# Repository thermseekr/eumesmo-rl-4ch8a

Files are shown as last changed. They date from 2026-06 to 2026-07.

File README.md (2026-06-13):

# eumesmo-rl-4ch8a

Relay board with 4x 24 VDC NO relays. This board is designed to be used togheter with [eumesmo-io-24v16ch](https://github.com/thermseekr/eumesmo-io-24v16ch), but can be driven by any 24V control circuit compatible with NPN inputs. It uses Omron 10A relays and is limited to 8A/channel per copper trace capacity.

The board is compatible with the SP7 DIN rail system from Metaltex.

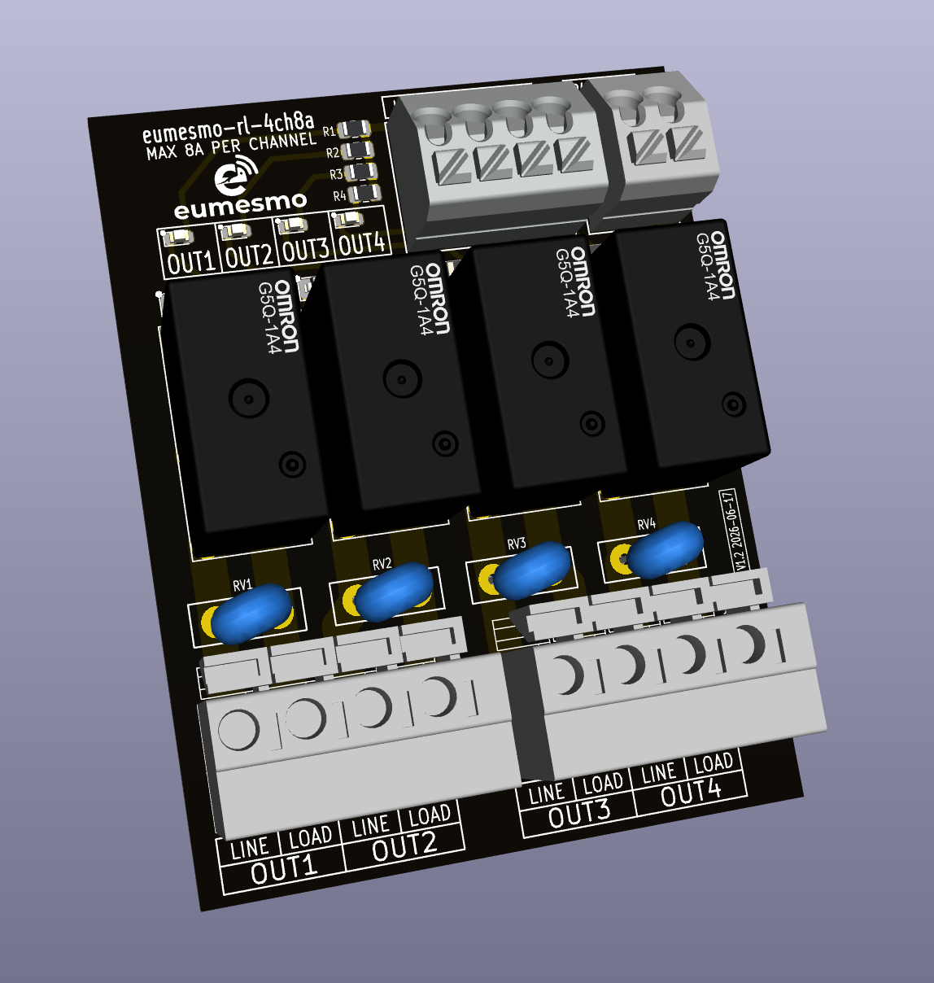
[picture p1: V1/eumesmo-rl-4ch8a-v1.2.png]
eumesmo-rl-4ch8a


## VERSION HISTORY

V1.2 - 2026/06/13 - Repository renamed from RELAY-24V-4CH-8A to eumesmo-rl-4ch8A to align the design with the eumesmo line of building automation products.

V1.1 - 2026/06/02 - Input terminal blocks replaced from 2.54mm to 3.5mm pitch for easier installation in the field.

V1.0 - 2024-11-23 - Initial release.

## LICENSE

This project is licensed under the [Creative Commons BY-NC 4.0 License](https://creativecommons.org/licenses/by-nc/4.0/).
Commercial use is not permitted without prior written consent. See the [LICENSE.txt](LICENSE.txt) file for details.

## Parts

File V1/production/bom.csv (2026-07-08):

Designator | Footprint | Quantity | Value | LCSC Part #
D1, D3, D5, D7 | 0603 | 4 | WHITE | C2290
D2, D4, D6, D8 | D_SOD-123 | 4 | 1N4148 | C81598
J1 | TerminalBlock_Wago_250-202_1x02_P3.5mm_45Degree | 1 | 250-202 | C2898744
J2 | TerminalBlock_Wago_250-204_1x04_P3.5mm_45Degree | 1 | 250-204 | C2898746
J3, J4 | TerminalBlock_Dibo_DB142V-5.08-4P_1x04_P5.08mm_Vertical | 2 | DB142V-5.08-4P | C2898701
K1, K2, K3, K4 | Relay_SPST_Omron-G5Q-1A | 4 | G5Q-1A4-DC24V | C2931104
R1, R2, R3, R4 | 0805 | 4 | 10k/125mW | C17414
RV1, RV2, RV3, RV4 | RV_Disc_D9.50mm_W3.6mm_P5.08mm | 4 | 275VAC | C2761646

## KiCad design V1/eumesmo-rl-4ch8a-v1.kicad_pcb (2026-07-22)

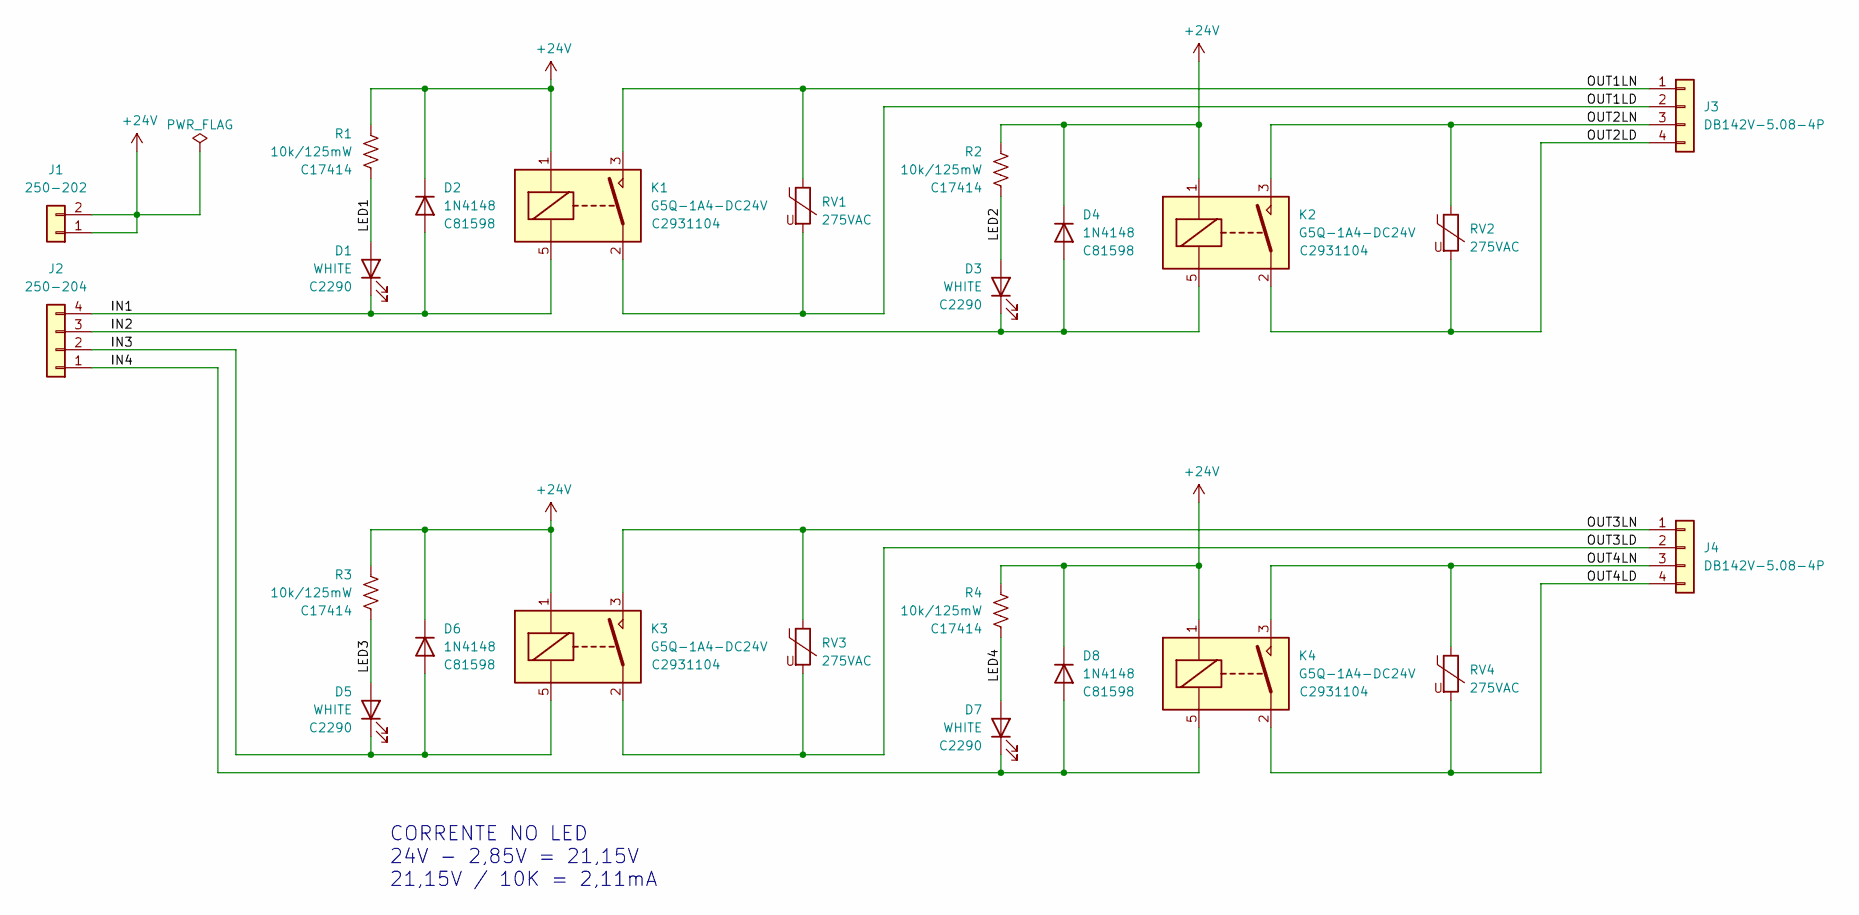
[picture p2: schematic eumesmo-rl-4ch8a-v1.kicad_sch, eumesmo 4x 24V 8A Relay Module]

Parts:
D1, D3, D5, D7: WHITE; LED_0603_1608Metric; Mfr PN KT-0603W; LCSC Part # C2290
D2, D4, D6, D8: 1N4148; D_SOD-123; Mfr PN 1N4148W; LCSC Part # C81598
J1: 250-202; TerminalBlock_Wago_250-202_1x02_P3.5mm_45Degree; Mfr PN DB141V-2.54-2P-GN; JLCPCB BOM 1
J2: 250-204; TerminalBlock_Wago_250-204_1x04_P3.5mm_45Degree; Mfr PN DB141V-2.54-4P-GN; JLCPCB BOM 1
J3, J4: DB142V-5.08-4P; TerminalBlock_Dibo_DB142V-5.08-4P_1x04_P5.08mm_Vertical; Mfr PN DB142V-5.08-4P-GN; JLCPCB BOM 1
K1, K2, K3, K4: G5Q-1A4-DC24V; Relay_SPST_Omron-G5Q-1A; Mfr PN G5Q-1A4-DC24V; JLCPCB BOM 1
R1, R2, R3, R4: 10k/125mW; R_0805_2012Metric; Mfr PN 0805W8F1002T5E; LCSC Part # C17414
RV1, RV2, RV3, RV4: 275VAC; RV_Disc_D9.50mm_W3.6mm_P5.08mm; Mfr PN RM07D431KC1IE100; JLCPCB BOM 1

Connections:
+24V: D2.1 (K), D4.1 (K), D6.1 (K), D8.1 (K), J1.1, J1.2, K1.1, K2.1, K3.1, K4.1, R1.1, R2.1, R3.1, R4.1
/IN1: D1.1 (K), D2.2 (A), J2.4, K1.5
/IN2: D3.1 (K), D4.2 (A), J2.3, K2.5
/IN3: D5.1 (K), D6.2 (A), J2.2, K3.5
/IN4: D7.1 (K), D8.2 (A), J2.1, K4.5
/LED1: D1.2 (A), R1.2
/LED2: D3.2 (A), R2.2
/LED3: D5.2 (A), R3.2
/LED4: D7.2 (A), R4.2
/OUT1LD: J3.2, K1.2, RV1.2
/OUT1LN: J3.1, K1.3, RV1.1
/OUT2LD: J3.4, K2.2, RV2.2
/OUT2LN: J3.3, K2.3, RV2.1
/OUT3LD: J4.2, K3.2, RV3.2
/OUT3LN: J4.1, K3.3, RV3.1
/OUT4LD: J4.4, K4.2, RV4.2
/OUT4LN: J4.3, K4.3, RV4.1

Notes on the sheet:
CORRENTE NO LED 24V - 2,85V = 21,15V 21,15V / 10K = 2,11mA

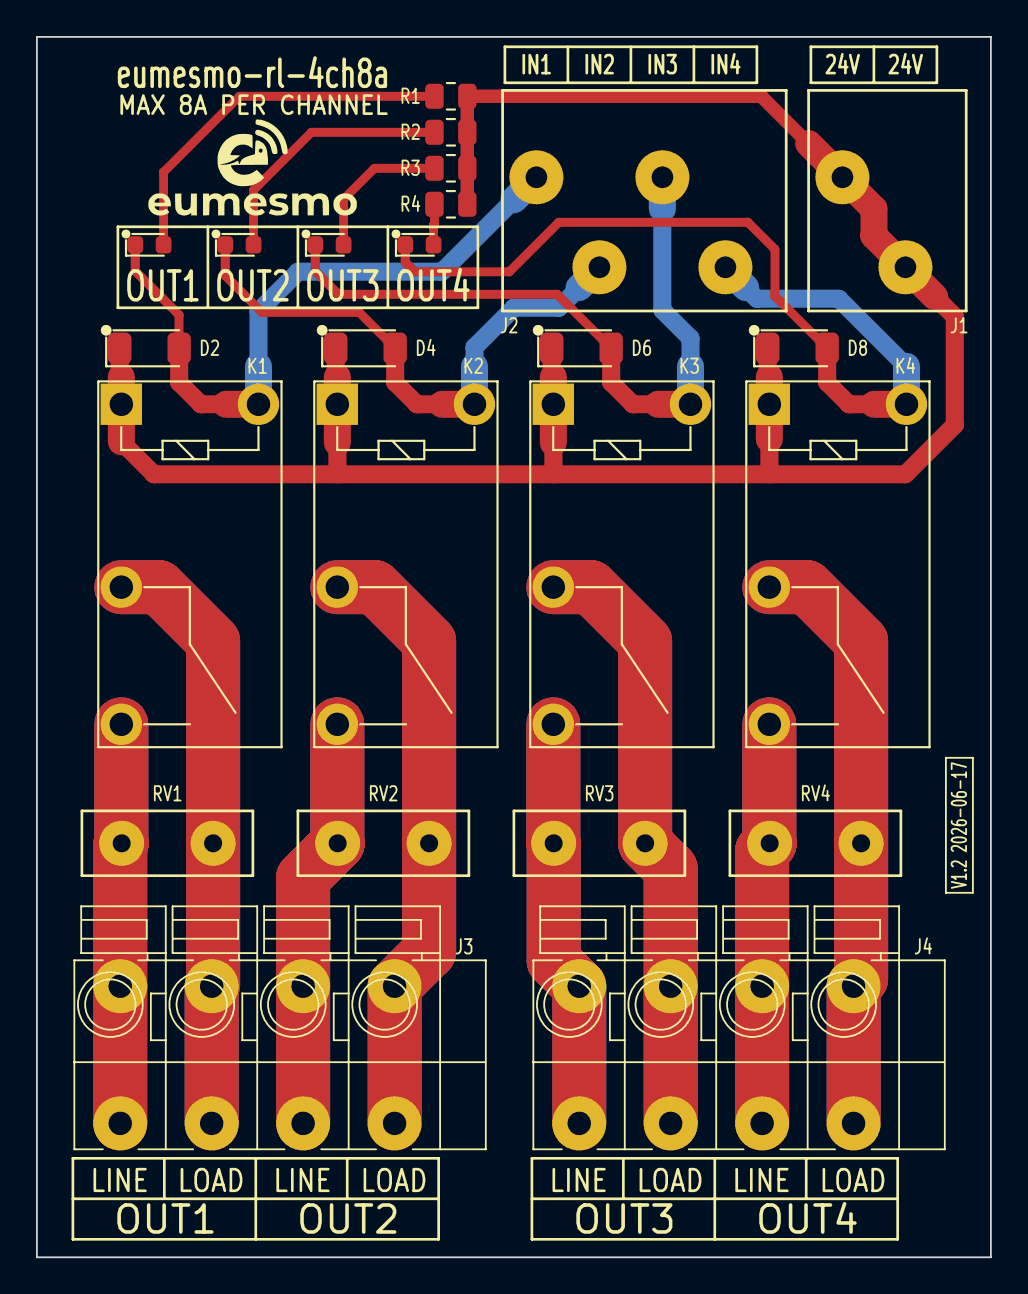
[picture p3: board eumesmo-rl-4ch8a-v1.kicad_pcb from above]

Board: 2 copper layers, 53.0 x 67.8 mm, 24 parts (0 on the bottom side), 17 nets.

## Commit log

2026-06-01 Replaced terminal blocks
    [relay-24v-4ch-8a-v1.kicad_pcb, relay-24v-4ch-8a-v1.kicad_sch]
2026-06-01 Replace terminal block
    [relay-24v-4ch-8a-v1.kicad_pcb]
2026-06-02 Adjusted file name convention
    [relay-24v-4ch-8a-v1.kicad_pcb]
2026-06-12 Replaced input terminal blocks for 3.5mm pitch.
    [relay-24v-4ch-8a-v1.kicad_pcb, relay-24v-4ch-8a-v1.kicad_sch]
2026-06-13 Renamed all files to match the eumesmo branding.
    [bom.csv, designators.csv, eumesmo-rl-4ch8a-v1.kicad_pcb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]
2026-06-13 Updated version numbers.
    [bom.csv, designators.csv, eumesmo-rl-4ch8a-v1.kicad_pcb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]
2026-06-17 Release V1.2.0
    [eumesmo-rl-4ch8a-v1.kicad_pcb, eumesmo-rl-4ch8a-v1.kicad_sch]
2026-07-08 Replaced 0603 size 10k resistors for 0805 size.
    [bom.csv, eumesmo-rl-4ch8a-v1.kicad_pcb, eumesmo-rl-4ch8a-v1.kicad_sch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]
2026-07-22 Plotted silkscreen in DXF for EPLAN
    [eumesmo-rl-4ch8a-v1.kicad_pcb]
